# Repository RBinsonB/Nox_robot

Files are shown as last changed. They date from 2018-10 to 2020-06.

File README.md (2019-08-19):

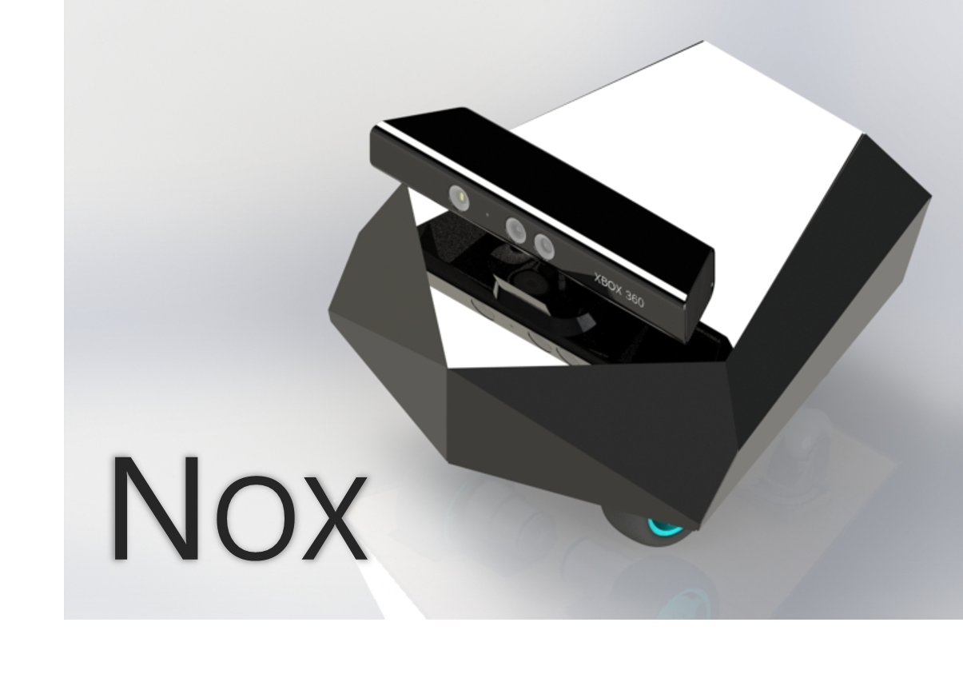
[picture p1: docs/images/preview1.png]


# Nox Robot project
Nox is a nice (and time-consuming for me) robot which uses SLAM (ROS) with a Kinect to navigate in its environment. It is powered by ROS running on a Raspberry Pi 3B and an Arduino that controls two motors with encoders.

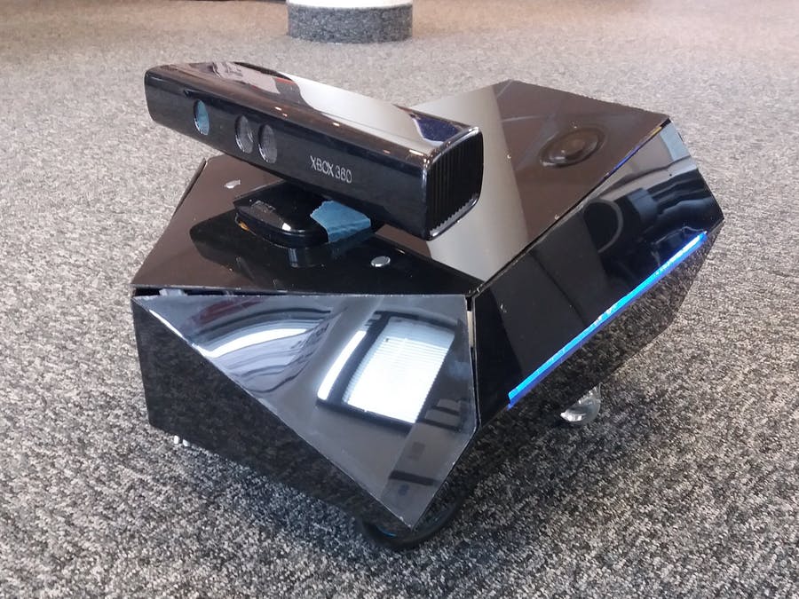
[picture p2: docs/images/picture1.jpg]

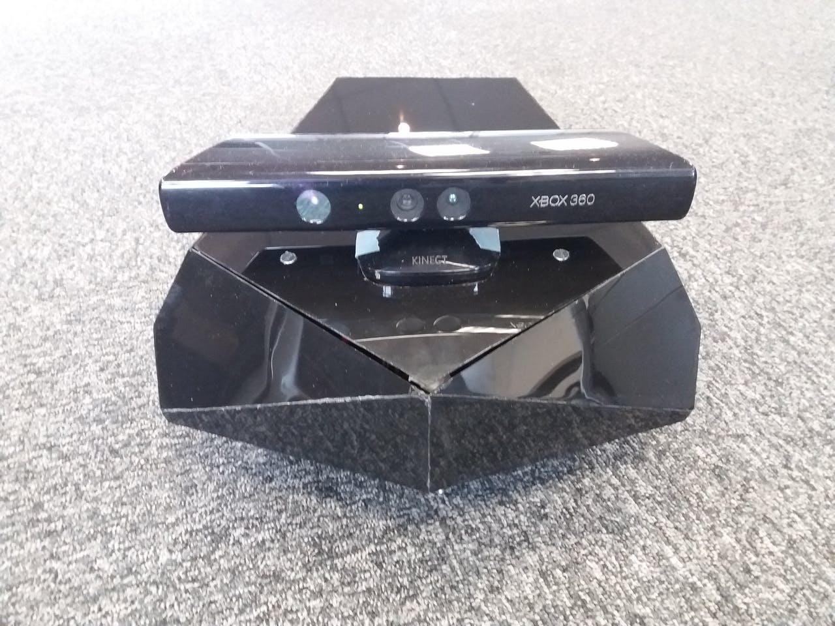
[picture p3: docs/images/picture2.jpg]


In its current state the robot can use SLAM (gmapping) to create a map of its surroundings (using the Kinect depth perception to detect wall and obstacles) and localize itself within the map. It can plan a path to a given goal and drive to it avoiding obstacles.

## Nox characteristics
Nox is a differential drive robot with the motors placed on the same axis. The base is made of wood with two caster wheels for support. The rest of the structure is made mainly of wood and metal brackets, easy to find in any DIY retail store. On the rear part of the robot plates can be stacked to put the electronic boards on.
More information (such as components used) can be found in the [Hackster page of the project](https://www.hackster.io/robinb/nox-a-house-wandering-robot-ros-652315).

### Schematics
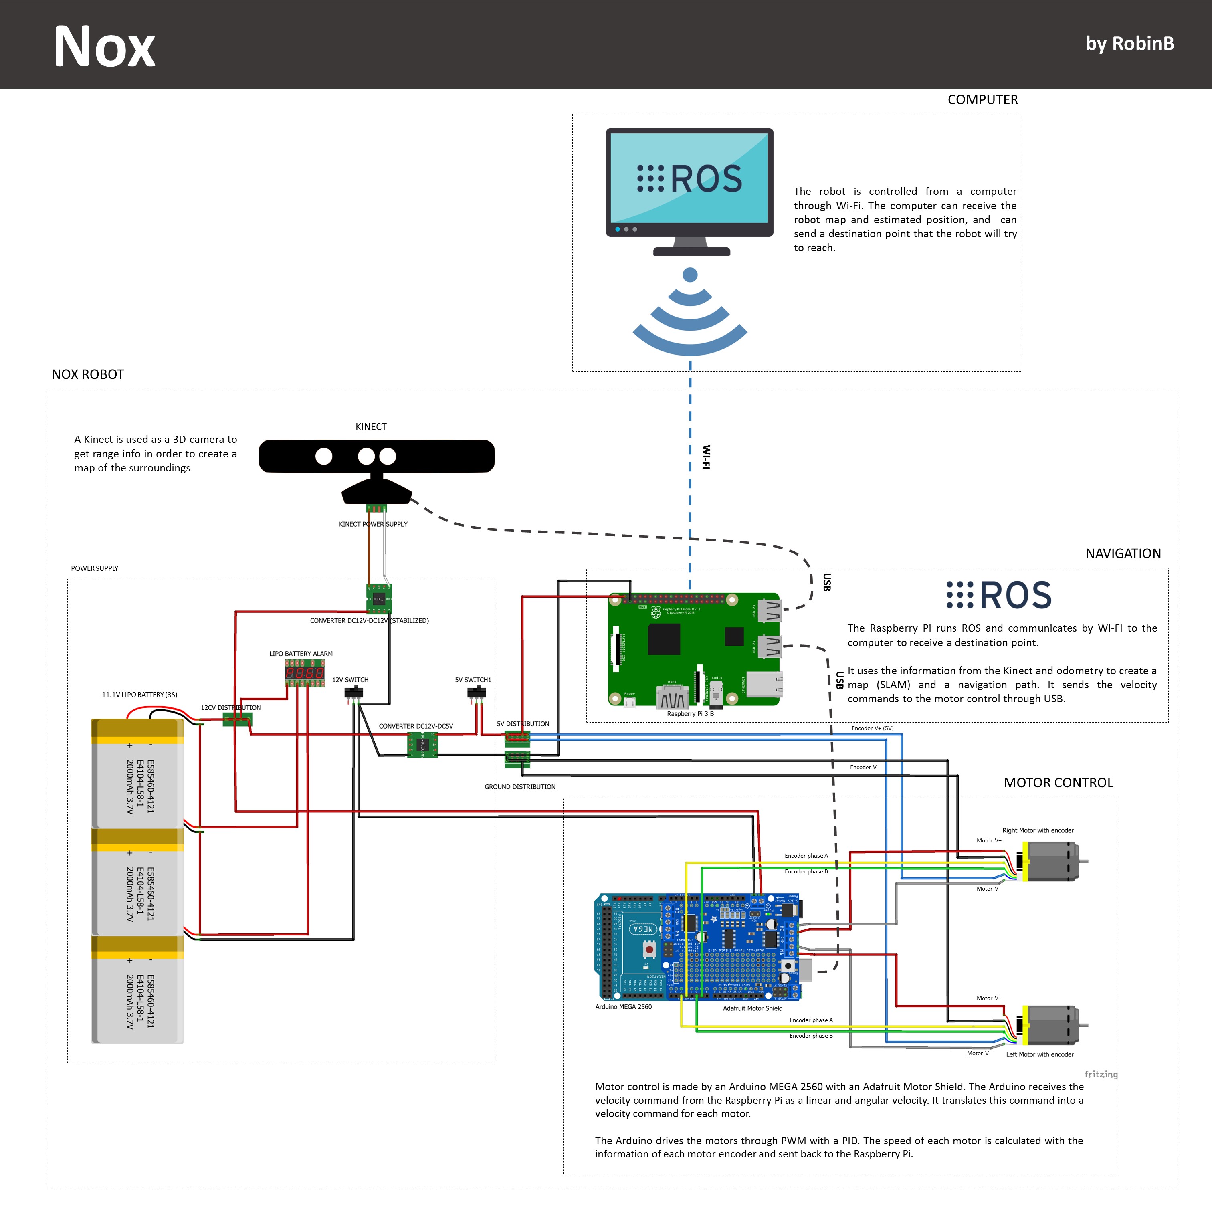
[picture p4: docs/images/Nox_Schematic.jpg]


### ROS packages
* #### nox_description:
This package includes the URDF description of the robot and the associated CAD files for display in RViz. The launch file "nox_rviz.launch" launches the joint and robot state publisher as well as RViz to display the model.
* #### nox:
This package includes the base controller node "nox_controller.cpp". This node will convert velocity command data into proper command data for the robot (according to the robot kinematic model) and send it to the Arduino Mega (through ROSSerial). It also computes the odometry (with the encoder data and according to the robot kinematic model) from data received from the Arduino Mega. The package also includes several launch files used to start the navigation (see "How to use Nox" below).
* #### Arduino:
The arduino node receives the command order from the base controller node and commands the motor speeds. It also sends back the encoder data needed for the odometry to the controller node through ROSSerial.

## How to use Nox
### Packages installation
The software for the Nox project was developped with ROS Kinetic and Ubuntu 16.04. More recent versions should work as well but might require some tweaking. This readme doesn't explain how to install ROS and packages. For more information you can check the [ROS tutorials](http://wiki.ros.org/ROS/Tutorials).

#### To use Nox you will need the following packages (most of them should already be installed by default or requested when building the nox packages):
* The [navigation stack](https://wiki.ros.org/navigation),
* The freenect package (for connecting to the Kinect)
* [RViz](http://wiki.ros.org/rviz)
* [TF](http://wiki.ros.org/tf), [Joint State](http://wiki.ros.org/joint_state_publisher) and [Robot State](http://wiki.ros.org/robot_state_publisher) Publishers
* [ROSSerial package](http://wiki.ros.org/rosserial) (for connecting to the Arduino Mega)
* [SLAM gmapping](https://wiki.ros.org/slam_gmapping).
* [TEB local planner](https://wiki.ros.org/teb_local_planner).

#### Installation
You can install and build the package by copying the "nox" and "nox_description" folders in "your_catkin_workspace/src" on both your computer and the Raspberry Pi and running:
  ```
  catkin_make
  ```

## Running Nox

In order to navigate Nox you will need to start two launch files using SSH and [ROS nodes over network](http://wiki.ros.org/ROS/NetworkSetup).
### 1. Connect to Nox Wi-Fi
I haven't included in my GitHub the RPi network configuration but basically the RPi creates an Ad-Hoc network I connect to with my computer in order to send SSH commands. It's also possible to connect both the Rpi and the computer to the same WiFi network. Once connected and before launching any ROS command you should sync the RPi to the computer using the following code in RPi:

`sudo ntpdate ip_address_of_the_computer`

You can also setup the ntpdate or use chrony to do that automatically.

### 2. Start the odometry and motor control
In the RPi, use the following command to start the main program:

`roslaunch nox nox_bringup.launch`

It will launch the serial controller node connected to the Arduino, the Kinect node, the odometry calculation node and the joint state publisher. If this step succeded you should see the side light of the robot going from a series of three quick blinks to a slow "breathing-like" type of blinking.

### 3. Start the navigation
In order to be able to do path planning calculation and mapping you have to use a launch file on your computer this time. Before doing so, assure yourself that you exported the ROS master from the RPi (modify the command to suit your own setup):

`export ROS_MASTER_URI=http://localhost:11311`

You can then launch:

`roslaunch nox nox_slam.launch`

It will launch the move_base node and RViz. By using the "2D Nav Goal" arrow you can give a goal for the robot to reach. Alternatively, you can use the ROS teleop keyboard to control the robot:

`rosrun teleop_twist_keyboard teleop_twist_keyboard.py` 

## Authors

* **Robin Baran** - *Initial work*

## License

This project is licensed under the GNU General Public License version 3

## Acknowledgments

* [Sungjik's project](https://sungjik.wordpress.com/2015/09/28/my_personal_robotic_companion/) which was the biggest inspiration to make my own robot
* ["ROS Navigation Tuning Guide"](http://kaiyuzheng.me/documents/navguide.pdf) by Kaiyu Zheng
* ["How to connect Kinect to Raspberry Pi 2 or 3 with ROS"](https://www.youtube.com/watch?v=_QpNMJEAkX0) Youtube video by Robotics Weekends
* ["Communication between Raspberry Pi and PC (ROS)"](https://github.com/mktk1117/six_wheel_robot/wiki/Communication-between-Raspberry-Pi-and-PC-(ROS)) by mktk1117
* ["On Differential Drive Robot Odometry with Application to Path Planning"](https://www.researchgate.net/publication/242389452_On_Differential_Drive_Robot_Odometry_with_Application_to_Path_Planning) by Evangelos Papadopoulos and Michael Misailidis
* [Turtlebot programs](https://github.com/ROBOTIS-GIT/turtlebot3)
* [Prof. Shuro Nakajima from Wakayama University](https://www.wakayama-u.ac.jp/~nakajima/) where I got the occasion to learn by working on the PMV (Personal Mobility Vehicle) project (check it it's awesome)
* Everyone in the ROS community who got the same problems as me and those who answered them

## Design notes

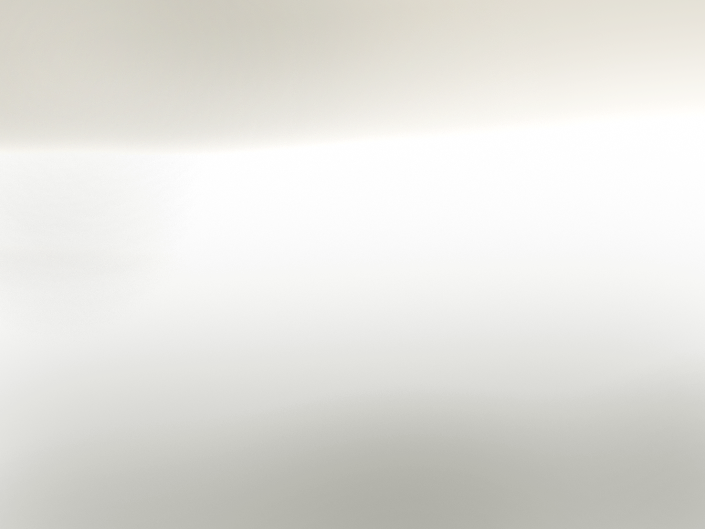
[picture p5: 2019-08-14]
CAD/Solidworks/Arduino Uno/snowcloud.png

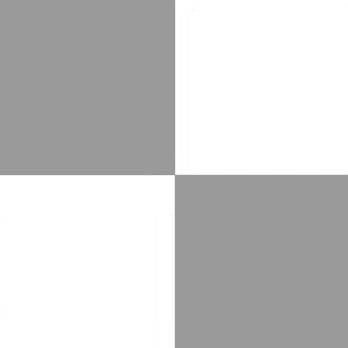
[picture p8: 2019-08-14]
CAD/Solidworks/Arduino Uno/checker3.jpg

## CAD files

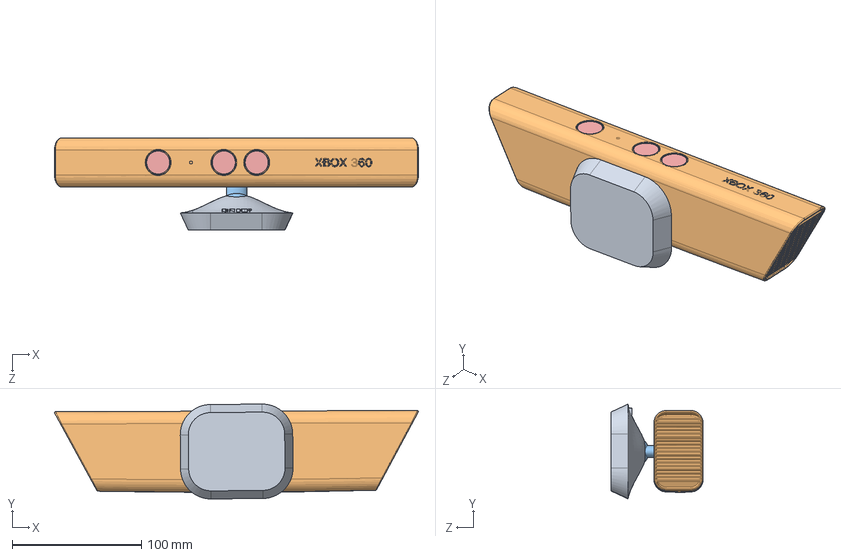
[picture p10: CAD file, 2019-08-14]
CAD/Solidworks/Kinect/kinect assembly.SLDASM
281.5 x 73.4 x 71.4 mm
kinect base
kinect
kinect pivot
kinect middle lightbulb x 2
kinect lens cover x 3

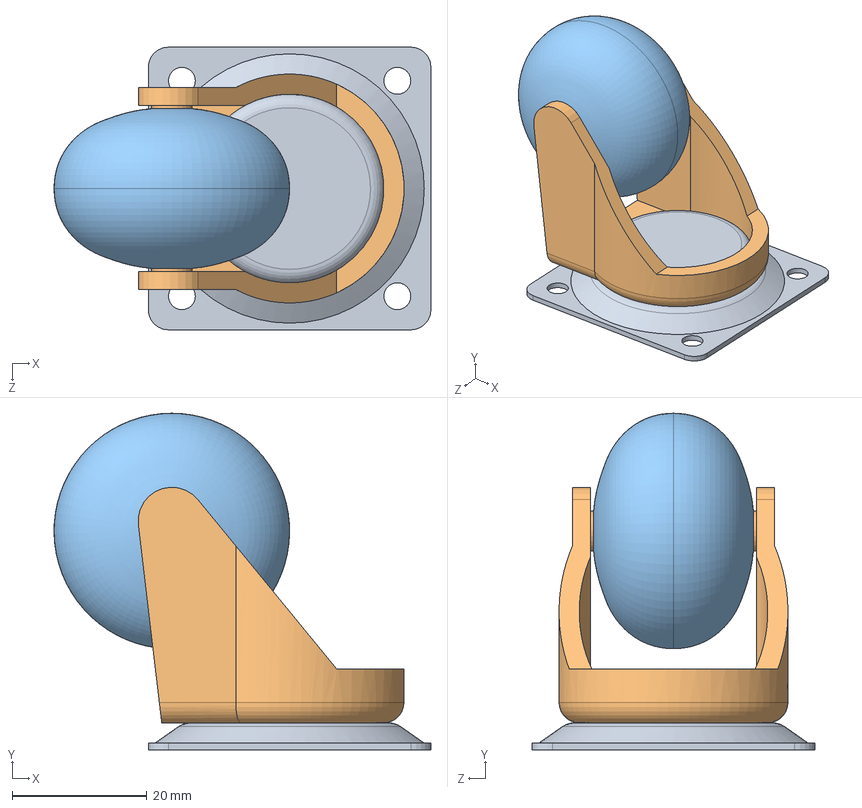
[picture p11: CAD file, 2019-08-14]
CAD/Solidworks/Pivoting roller/Pivoting_roller.SLDASM
56.0 x 50.0 x 42.0 mm
roller_base
Pivot
Roller

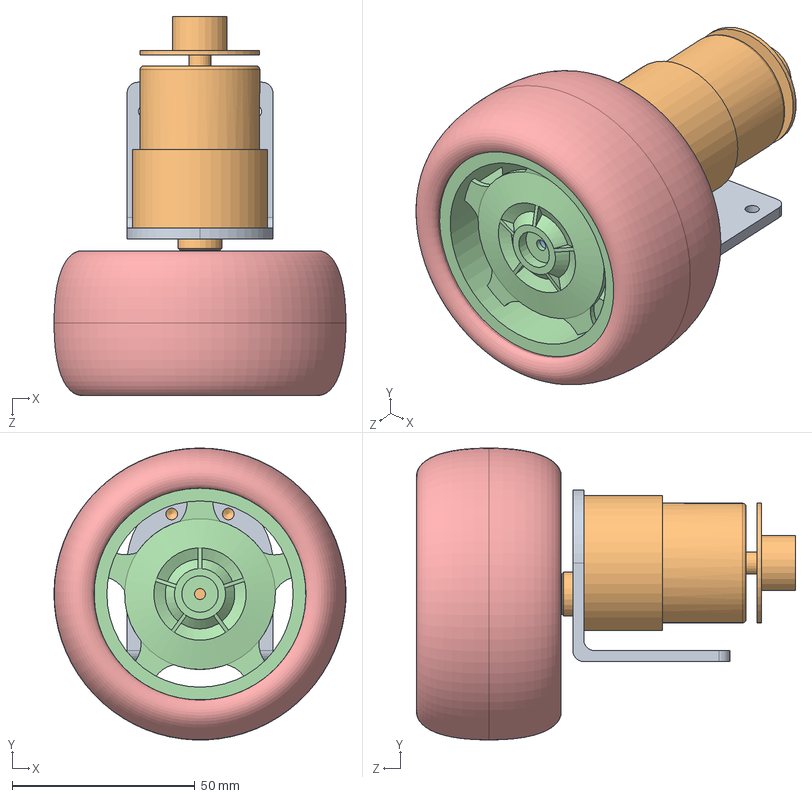
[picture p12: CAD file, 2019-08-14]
CAD/Solidworks/Motor/Motor_assembly.SLDASM
80.0 x 80.0 x 103.8 mm
Support
Moteur
Attache_moteur
Roue
Pneu

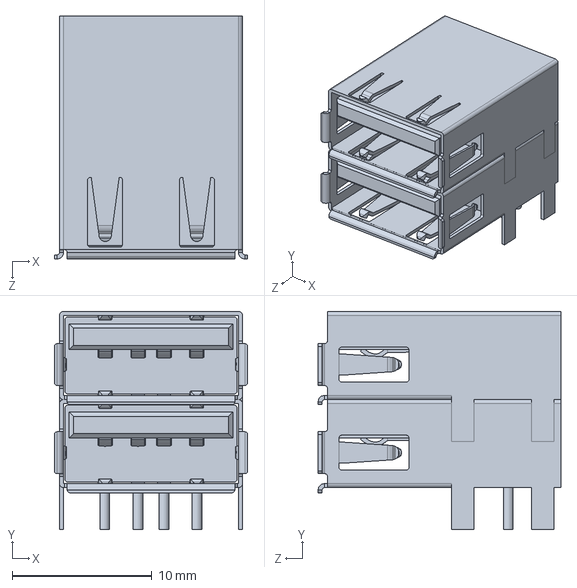
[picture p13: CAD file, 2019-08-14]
CAD/Solidworks/Raspberry Pi Model B 3/dual_usb.SLDASM
13.8 x 15.6 x 17.4 mm
USB port x 2

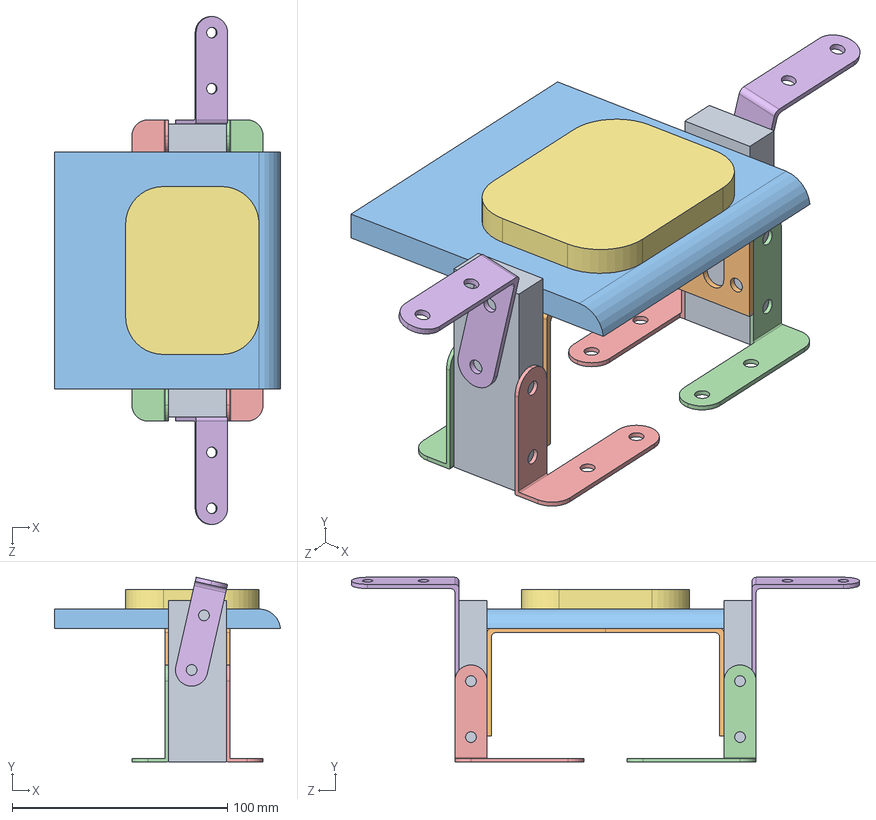
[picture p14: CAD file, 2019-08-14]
CAD/Solidworks/Kinect support/Kinect support.SLDASM
105.0 x 85.8 x 236.0 mm
wood_block x 2
Mounting_bracket_50 x 2
wood_planck_kinect
Angle iron left x 2
Angle iron right x 2
Angle small 50 x 2
wedge_kinect

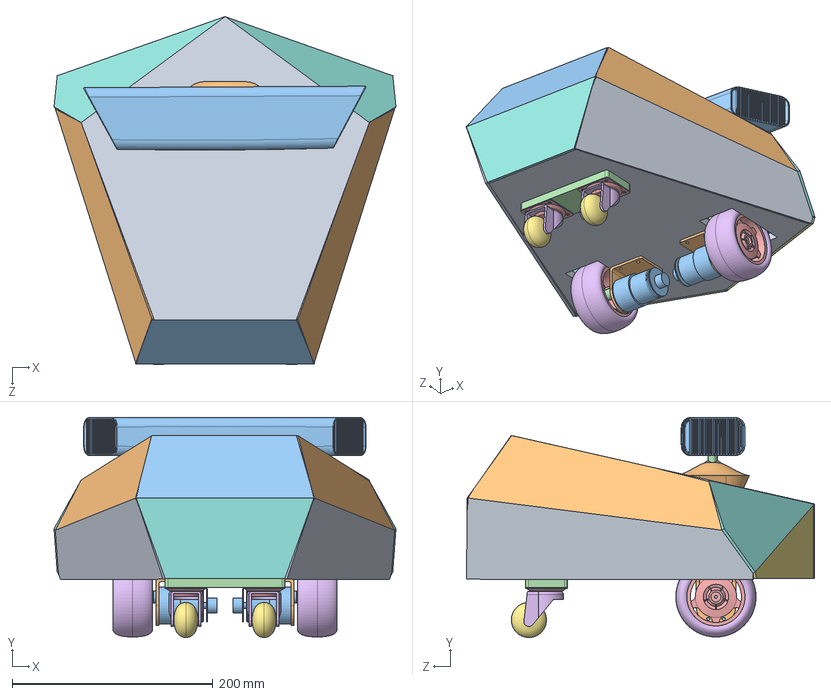
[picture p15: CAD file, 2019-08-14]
CAD/Solidworks/Nox.SLDASM
341.0 x 219.4 x 347.0 mm
base
Support x 2
Moteur x 2
Attache_moteur x 2
Roue x 2
Pneu x 2
Front_left x 2
Front_left_superior x 2
Top
kinect base
kinect
kinect pivot
kinect middle lightbulb x 2
kinect lens cover x 3
Battery_11v
Rear
Left_bottom x 2
Left_top x 2
Rear_top
Mounting_bracket x 4
PCB
rj45 port
USB port x 4
pins
audio jack
15pin FFC x 2
ffc lid x 2
wood_block x 2
Mounting_bracket_50 x 2
wood_planck_kinect
Angle iron left x 2
Angle iron right x 2
Angle small 50 x 2
wedge_kinect
rear_support
Roller_wedge
roller_base x 2
Pivot x 2
Roller x 2
Angle small 30 x 4
Electronic support
Frame_front_left_1 x 2
Frame_front_left_2 x 2
Frame_front_left_3 x 2
Frame_front_left_5 x 2
Frame_front_center_1
Frame_front_center_2
Frame_left_1
Frame_left_2 x 3
Frame_left_3
Frame_rear_1 x 2

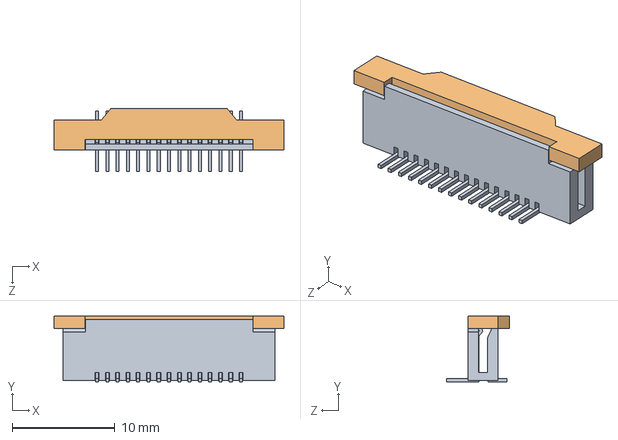
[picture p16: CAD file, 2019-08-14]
CAD/Solidworks/Raspberry Pi Model B 3/FFC.SLDASM
22.4 x 6.38 x 6.11 mm
15pin FFC
ffc lid

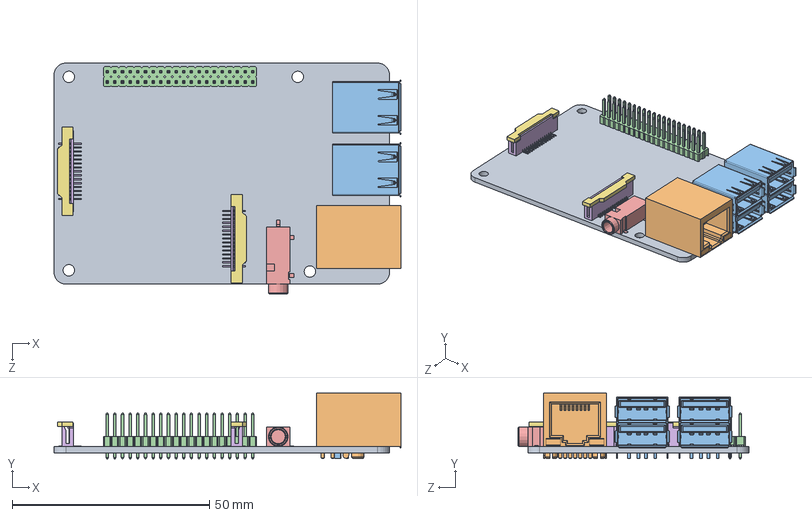
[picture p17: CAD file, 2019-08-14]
CAD/Solidworks/Raspberry Pi Model B 3/raspberry pi model B+.SLDASM
87.9 x 16.6 x 58.5 mm
PCB
rj45 port
USB port x 4
pins
audio jack
15pin FFC x 2
ffc lid x 2

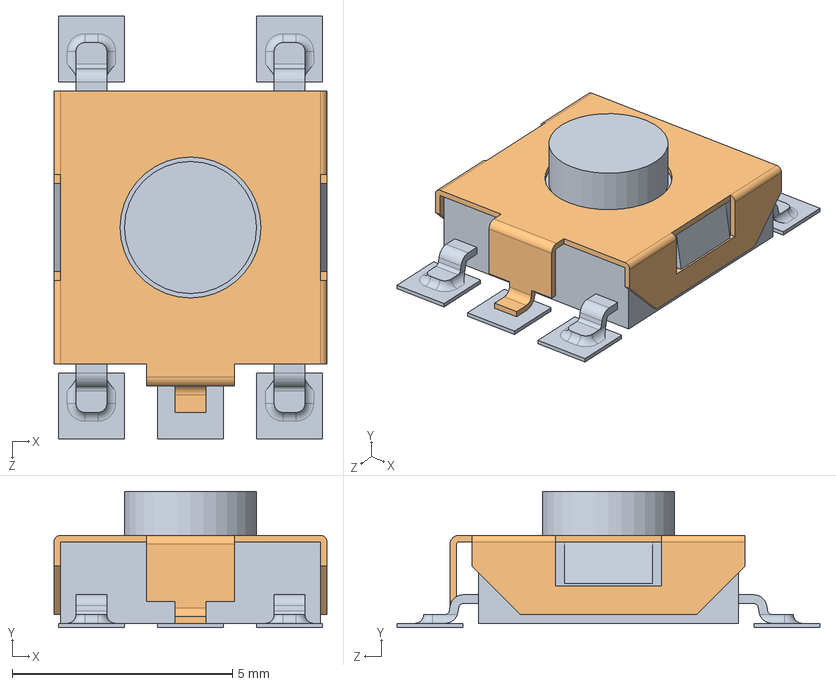
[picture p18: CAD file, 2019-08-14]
CAD/Solidworks/Arduino Uno/RESET BUTTON.SLDASM
6.20 x 3.10 x 9.60 mm
RESET CORE
RESET

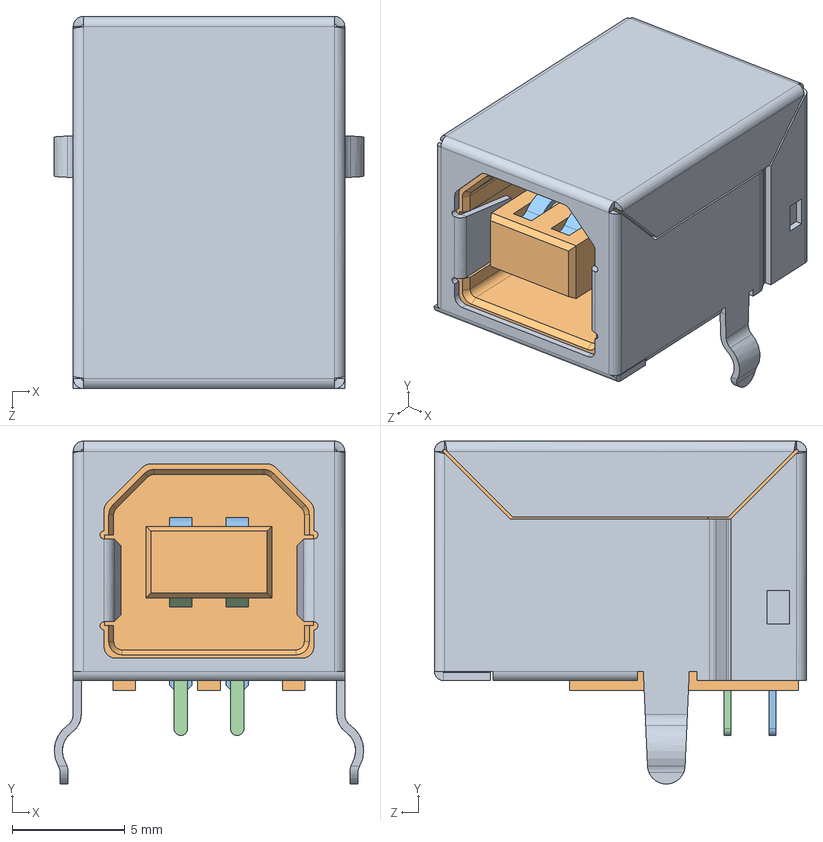
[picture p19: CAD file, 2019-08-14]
CAD/Solidworks/Arduino Uno/USB type b.SLDPRT.SLDASM
13.7 x 15.2 x 16.5 mm
USB SHELL
USB core
usb top contact x 2
usb btm contact x 2

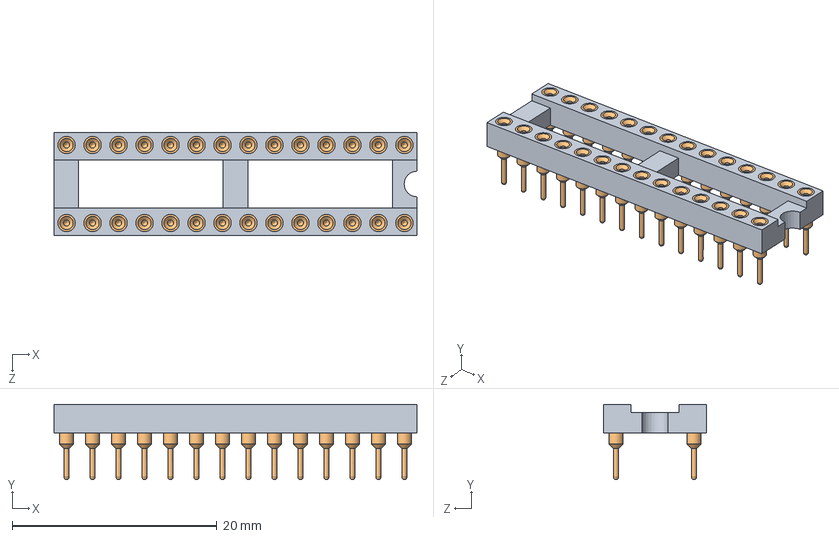
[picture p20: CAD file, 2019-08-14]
CAD/Solidworks/Arduino Uno/dip28.SLDASM
35.5 x 7.37 x 10.1 mm
dip28
dip socket pin x 28

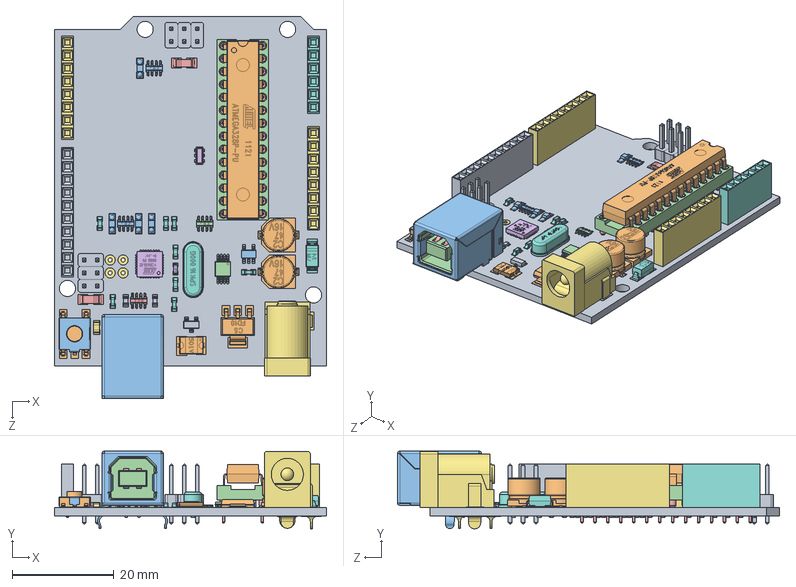
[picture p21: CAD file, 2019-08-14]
CAD/Solidworks/Arduino Uno/arduino uno.SLDASM
53.3 x 15.2 x 74.9 mm
unoboard blue
47uf CAP Dcase x 2
USB SHELL
USB core
usb top contact x 2
usb btm contact x 2
power jack
crystal
2pin_header__02 x 6
nano - reg
led x 4
dip28
dip socket pin x 28
atmega16u2
8 PORT HEADER x 2
6 PORT HEADER
10 PORT HEADER
ATMEL328P
102 RESISTOR PACK x 2
103 RESISTOR PACK
220 RESISTOR PACK
16mhz crystal - measured
PADS001
603 cap on pad x 8
ssot3
mf-msmf050-2
lmv358
lp2985dgkr
cd1206 diode x 2
603 resistor
blm21
m7 diode
MLC0603 x 2
RESET CORE
RESET

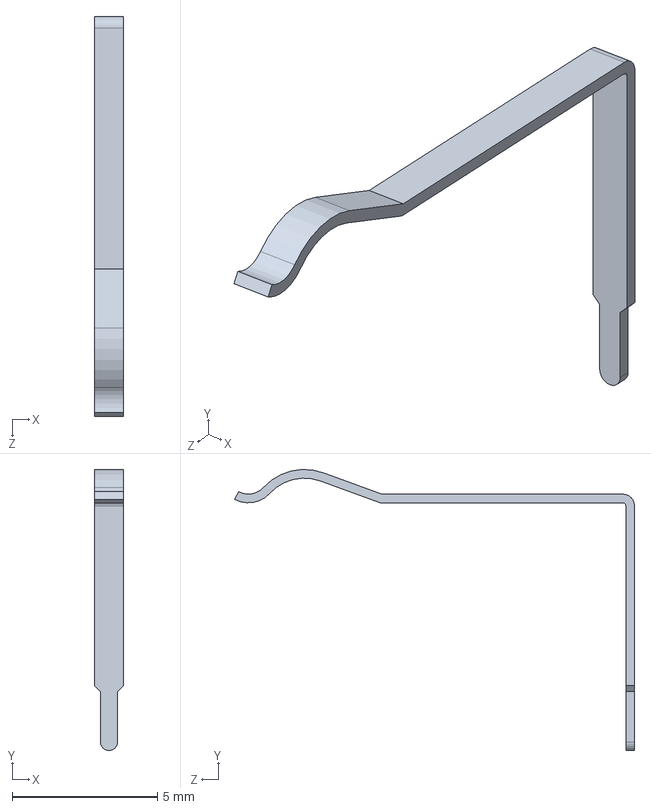
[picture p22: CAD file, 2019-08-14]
CAD/Solidworks/Arduino Uno/usb top contact.SLDPRT
1.00 x 9.67 x 13.8 mm

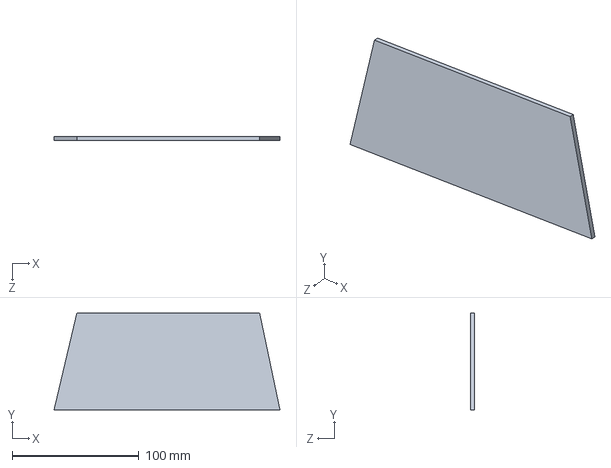
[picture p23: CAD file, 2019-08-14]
CAD/Solidworks/Carter/Rear_top.sldprt
178.2 x 76.4 x 3.00 mm

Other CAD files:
CAD/Solidworks/Frame_front_left_3.sldprt
CAD/Solidworks/Kinect support/wood_planck_kinect.SLDPRT
CAD/Solidworks/Motor/Attache_moteur.SLDPRT
CAD/Solidworks/Pivoting roller/Roller.SLDPRT
CAD/Solidworks/Angle small 30.SLDPRT
CAD/Solidworks/Angle small 50.SLDPRT
CAD/Solidworks/Arduino Uno/10 PORT HEADER.SLDPRT
CAD/Solidworks/Arduino Uno/102 RESISTOR PACK.SLDPRT
CAD/Solidworks/Arduino Uno/103 RESISTOR PACK.SLDPRT
CAD/Solidworks/Arduino Uno/16mhz crystal - measured.SLDPRT
CAD/Solidworks/Arduino Uno/220 RESISTOR PACK.SLDPRT
CAD/Solidworks/Arduino Uno/2pin_header__02.sldprt
CAD/Solidworks/Arduino Uno/47uf CAP Dcase.SLDPRT
CAD/Solidworks/Arduino Uno/6 PORT HEADER.SLDPRT
CAD/Solidworks/Arduino Uno/603 cap on pad.SLDPRT
CAD/Solidworks/Arduino Uno/603 resistor.SLDPRT
CAD/Solidworks/Arduino Uno/8 PORT HEADER.SLDPRT
CAD/Solidworks/Arduino Uno/ATMEL328P.SLDPRT
CAD/Solidworks/Arduino Uno/MLC0603.SLDPRT
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

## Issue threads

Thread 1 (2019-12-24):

arduino firmware

bekirbostanci, 2019-12-24:
Hello
Your arduino firmware there is lots of different variable and some constant values. Some of them don't have any comment. Can you write comment for these lines ?
```
//990 and 1000 ?
speed_act_left=((pos_left/990)*2*PI)*(1000/LOOPTIME)*radius;   

//0.882 and 0.00235 ?
PWM_leftMotor = constrain(((speed_req_left+sgn(speed_req_left)*0.0882)/0.00235) + (speed_cmd_left/0.00235), -255, 255);
```

bekirbostanci, 2019-12-27:
0.00235 is a scale factor to turn the speed in m/s into PWM value (0 to 255)
The coefficient is a slof of the pwm and cmd value.
Second coefficient is dead range of the motor driver so that we are adding sgn(speed_req_left)*0.0882
Thanks @RBinsonB

Closed 2019-12-27.

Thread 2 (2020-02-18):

Wiring diagram does not agree with arduino code

madgrizzle, 2020-02-18:
I think the wiring diagram shows pins 2, 3, 5, & 6 being used for the encoder inputs but the arduino code uses 2, 3, 4, & 5.  Made my robot go in circles on rviz.

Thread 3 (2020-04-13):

RPi lanch problem

DPiero, 2020-04-13:
Hi,
forgive my english .. it's really bad ..
I have a problem with your project.
when i launch roslaunch nox nox_bringup.launch on Rpi
everything is ok except this:
[joint_state_publisher-1] process has died [pid 3887, exit code -6, cmd /home/ubuntu/catkin_ws/src/joint_state_publisher/joint_state_publisher/scripts/joint_state_publisher __name:=joint_state_publisher __log:=/home/ubuntu/.ros/log/b7e3dfe8-7d05-11ea-9aa0-080027e45c80/joint_state_publisher-1.log].
log file: /home/ubuntu/.ros/log/b7e3dfe8-7d05-11ea-9aa0-080027e45c80/joint_state_publisher-1*.log
since odometry doesn't work, could this be the problem?

bekirbostanci, 2020-04-13:
Hi Piero
Our repo only include arduino code. There is not a launcher in my pid dc
motor project.
So that I dont know how can I help you
Can you describe little bit more your problem

DPiero <notifications@github.com>, 13 Nis 2020 Pzt, 03:17 tarihinde şunu
yazdı:

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

2sekFPV, 2020-08-19:
Hi all !!!

Awsome project, thanks a lot for sharing :-)

But I'm facing the same issue with the joint state publisher dying... and so in Rviz I've got both "No transform from kinect to base_link" and "No transform from wheel_left to base_link"...

nbaddorf, 2020-11-17:
I think that I found out how to solve your problem. if you go into Nox_robot/nox/launch/nox_bringup.launch look for where it says gui and then True. chainge the True to False and that fixed it for me.

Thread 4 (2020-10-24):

arduino code

Ktysai, 2020-10-24:
Hello!

A wonderful job! Can you help me a little bit with the speed_to_pwm ration. How did you obtain it?

All the best!

bekirbostanci, 2020-10-24:
Hi @Ktysai
const double speed_to_pwm_ratio = 0.00235;    //Ratio to convert speed (in m/s) to PWM value. It was obtained by plotting the wheel speed in relation to the PWM motor command (the value is the slope of the linear function).

In the ros we are use cmd_vel topics for the control diff drive robots. That cmd_vel topics message type is  geometry_msgs::Twist  and this message include linear_x and angular_z. You can calculate motor speeds for this information. That is the first part.

We are coming your question. What is the speed_to_pwm_ratio constant. This constant convert wheel speed to pwm. Firstly you have to give 255 pwm your motor and detect the your motor max rpm. That is your max motor speed. After this process you have to calculate your circumference of the wheel. 2*pi*your_wheel_radius. After circumference*(rpm/60) give meter/sec. This is your speed but still this unit is not pwm.

Result :
For example my max speed 1 m/sec. Computer send the 1 m/sec with cmd_vel I have convert the pwm with this constant. If we know the max_rpm of my motor I can calculate this coefficient.
 ```
circumference = 2*pi*your_wheel_radius
max_speed = circumference*(max_rpm/60)
speed_to_pwm_ratio = (max_speed/255)
```

 I tried to explain in detail as much as I could, if there is another topic I can help with,  feel free to ask.

Ktysai, 2020-10-24:
@bekirbostanci  👍
Lovely explanation and an over all good project for ROS beginners as my self! The ROS is not that problematic as hardware interface :)

Practically you've given it a test in real life, not the specification given by the manufacturer. I guess the test is with no load, with wheels not touching the surface.

The minimum speed is tested with the robot with all the components mounted?

I was testing the Sungjik version with some modifications of the project, but sometimes with a joystick command
given in ROS, the wheels were rolling a little bit in the opposite direct of the movement and then were ok, with the right speed and direction. The <PID_v1.h> seems to work well here.

In my case I use an Leonardo clone and I'll have to do some tweaking since the dinamic memory is used a lot the by program.

When I've tested the robot I've had a encoder malfunction and the wheel was starting to go wild due to PID. I'll try to do a nocommloop thingy, that I've seen it's implemented here like `if no_encoder_ticks AND PWM_command is_not 0, then PWM = 0`. Is the proper way?

Thanks for the work and for in for provided!

All the best,
Ktysai

bekirbostanci, 2020-10-24:
It has been a long time since I used this project. As far as I remember, although we used a brushed dc motor, the result was not very efficient although the pid worked correctly. If you think your data from your encoders are incorrect and the encoder counts incorrectly, it is quite natural that the motor will speed up and cannot be controlled. Since the parameter you will enter here will be the same for 2 wheels and it will be balanced with pid, I think you do not need to adjust it very precisely.

Ktysai, 2020-10-24:
No, problem!

I want to go into the BLDC, but the ones with encoders aren't that cheap, plus a proper controllers, so for tests I'll still use them.
With BLDC, the torque is really high even at low speeds?

bekirbostanci, 2020-10-24:
Yes normally bldc motors torque control is not very easy task. There are some different methods for example foc field oriented control. You can search if you want to control more properly

Ktysai, 2020-10-27:
I know you've said it was a long time ago since the code was developed., but maybe you have a hint.

A big chunk of my code is based on yours, but I've had a lot of trouble in making the motor to obey the maximum speed.

The following line: **speed_cmd_left** is used to control the, but the motor speed exceeds the maxim speed.

https://github.com/RBinsonB/Nox_robot/blob/d7c528e78952625da7269b7a0c0fdce362763913/Arduino/motor_controller_v2_AFMS/motor_controller_v2_AFMS.ino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

If the **speed_cmd_left** is changed with **speed_req_left** the speed of the motor is properly constrained.

Is there something that i miss in my code?

bekirbostanci, 2020-10-27:
Hi again
This line only limited your cmd_left value.
speed_cmd_left = constrain(speed_cmd_left, -max_speed, max_speed);

Actually I don't know the problem completely know. If your encoder get true value and kp ki kd values are appropriate,  bellow line code should  convert your speed value to pwm.
`PWM_leftMotor = constrain(((speed_req_left+sgn(speed_req_left)*min_speed_cmd)/speed_to_pwm_ratio) + (speed_cmd_left/speed_to_pwm_ratio), -255, 255); `

If you are know limited your motor speed somethings goes to wrong. Maybe encoders not count all pulse but it is unlikely.
But you can check your encoder this way. Write a small arduino code and give motor to 255 pwm and encoders also count all pulse. Before the starting code  keep a counter ready and start both arduino code and counter at the same time check how many pulses you get after 60 seconds and calculate the expected value and compare your expected value and measured total pulse. If this 2 values are close pid values is not correct I think.

Ktysai, 2020-10-31:
@bekirbostanci, thanks again!

If I look at the rostopic "speed", **speed_req_left** & **speed_req_left** looks as expected. **speed_cmd_left** is changing very fast, but the numbers usually are far beyond the required speed, no matter what maximum speed is specified. Maybe is a displaying issue, since the topic is not refreshed that often. I have not used the serial of arduino to debug, yet :((

Encoders seems to be ok, I'll recheck them anyway, since it's easy to have a mismatched constant there. I'm using **[these](https://www.pololu.com/product/4753)** motors.

I'll have to recheck the code again, to be sure that there's no improper ratio involved. At the moment with **speed_req_left** constrained the code works.

The idea of constraining the **speed_req_left**  was born after seeing that **speed_cmd_left** might be already constrained by this line.
https://github.com/RBinsonB/Nox_robot/blob/d7c528e78952625da7269b7a0c0fdce362763913/Arduino/motor_controller_v2_AFMS/motor_controller_v2_AFMS.ino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

In any case, a lovely code that helps a lot development.

All the best!

Agri-Mechatronic, 2022-08-02:
> It has been a long time since I used this project. As far as I remember, although we used a brushed dc motor, the result was not very efficient although the pid worked correctly. If you think your data from your encoders are incorrect and the encoder counts incorrectly, it is quite natural that the motor will speed up and cannot be controlled. Since the parameter you will enter here will be the same for 2 wheels and it will be balanced with pid, I think you do not need to adjust it very precisely.

Hello, can we use differential drive (diff_tf.py) instead of nox_controller.cpp.If yes do you think that will effect in efficiency.Thanks.

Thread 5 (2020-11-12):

USING WITH RPLIDAR A1.

manhtran98bg, 2020-11-12:
Hi, i am doing an project like you project but i have used RPlidar A1 instead KINECT. So i want to ask you how to create launch file to use with RPlidar A1( i use motor with encoder  and arduino + pi3 like you). Pls help me! Thanks you very much!

Agri-Mechatronic, 2022-08-02:
> Hi, i am doing an project like you project but i have used RPlidar A1 instead KINECT. So i want to ask you how to create launch file to use with RPlidar A1( i use motor with encoder and arduino + pi3 like you). Pls help me! Thanks you very much!

Did you solve the problem? If yes can u answer please i am trying to do same project like yours.

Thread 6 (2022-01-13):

Adding IMU

adityasivaraj, 2022-01-13:
Hi Robin,

I am working on a similar project. I am also using Arduino to give the motor commands. Do you think I should add IMU to the RasPi directly (using GPIO pins) or I should add it to Arduino, which is already controlling the motor?

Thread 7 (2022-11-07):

LOST SYNC WITH DEVICE

Priyam1204, 2022-11-07:
WHen connecting to rplidar and running the  launch file, one error keeps on coming i.e., *LOST SYN TO DEVICE, RESTARTING*

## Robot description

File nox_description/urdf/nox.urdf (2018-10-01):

<?xml version="1.0"?>
	<robot name="nox">
		<link name="base_link">
			<visual>
				<origin rpy="1.57075 0 -1.57075" xyz="0.095 0.1664 0.05"/>
				<geometry>
					<mesh filename="package://nox_description/meshes/base.STL" scale="0.001 0.001 0.001"/>
				</geometry>
				<material name="black">
       			<color rgba="0.1 0.1 0.1 1"/>
     			</material>
			</visual>
		</link>

		<link name="motor_left">
			<visual>
				<origin rpy="-1.57075 0 0" xyz="-0.02 -0.061 0"/>
				<geometry>
					<mesh filename="package://nox_description/meshes/motor.STL" scale="0.001 0.001 0.001"/>
				</geometry>
				<material name="grey">
       			<color rgba="0.3 0.3 0.3 1"/>
     			</material>
			</visual>
		</link>

		<joint name="base_link_to_motor_left" type="fixed">
			<parent link="base_link"/>
			<child link="motor_left"/>
			<origin xyz="0 0.07 0.059"/>
		</joint>
		
		<link name="motor_right">
			<visual>
				<origin rpy="-1.57075 0 3.14159" xyz="0.02 0.061 0"/>
				<geometry>
					<mesh filename="package://nox_description/meshes/motor.STL" scale="0.001 0.001 0.001"/>
				</geometry>
				<material name="grey"/>
			</visual>
		</link>

		<joint name="base_link_to_motor_right" type="fixed">
			<parent link="base_link"/>
			<child link="motor_right"/>
			<origin xyz="0 -0.07 0.059"/>
		</joint>
		
		<link name="wheel_left">
			<visual>
				<origin rpy="1.57075 0 0" xyz="-0.04 0.02 -0.04"/>
				<geometry>
					<mesh filename="package://nox_description/meshes/wheel.STL" scale="0.001 0.001 0.001"/>
				</geometry>
				<material name="wheel_color">
       			<color rgba="0.06 0.25 0.25 1"/>
     			</material>
			</visual>
		</link>	
			
		<joint name="motor_left_to_wheel_left" type="continuous">
			<parent link="motor_left"/>
			<child link="wheel_left"/>
			<origin xyz="0 0.023 -0.019"/>
			<axis xyz="0 1 0"/>
		</joint>
		
		<link name="wheel_right">
			<visual>
				<origin rpy="1.57075 0 0" xyz="-0.04 0.02 -0.04"/>
				<geometry>
					<mesh filename="package://nox_description/meshes/wheel.STL" scale="0.001 0.001 0.001"/>
				</geometry>
				<material name="wheel_color"/>
			</visual>
		</link>	
			
		<joint name="motor_right_to_wheel_right" type="continuous">
			<parent link="motor_right"/>
			<child link="wheel_right"/>
			<origin xyz="0 -0.023 -0.019"/>
			<axis xyz="0 1 0"/>
		</joint>
		
		<link name="support_wheel_left">
			<visual>
				<origin rpy="-1.57075 0 1.57075" xyz="-0.021 -0.021 0"/>
				<geometry>
					<mesh filename="package://nox_description/meshes/support_wheel.STL" scale="0.001 0.001 0.001"/>
				</geometry>
				<material name="transparent_grey">
       			<color rgba="0.25 0.25 0.25 0.7"/>
     			</material>
			</visual>
		</link>	
			
		<joint name="base_link_to_support_wheel_left" type="fixed">
			<parent link="base_link"/>
			<child link="support_wheel_left"/>
			<origin xyz="-0.124 0.039 0.05"/>
		</joint>
		
		<link name="support_wheel_right">
			<visual>
				<origin rpy="-1.57075 0 1.57075" xyz="-0.021 -0.021 0"/>
				<geometry>
					<mesh filename="package://nox_description/meshes/support_wheel.STL" scale="0.001 0.001 0.001"/>
				</geometry>
				<material name="transparent_grey"/>
			</visual>
		</link>	
			
		<joint name="base_link_to_support_wheel_right" type="fixed">
			<parent link="base_link"/>
			<child link="support_wheel_right"/>
			<origin xyz="-0.124 -0.039 0.05"/>
		</joint>
		
		<link name="kinect">
			<visual>
				<origin rpy="0 0 1.57075" xyz="0.03 -0.14 0.04"/>
				<geometry>
					<mesh filename="package://nox_description/meshes/kinect_sensor.stl" scale="0.01 0.01 0.01"/>
				</geometry>
				<material name="black"/>
			</visual>
		</link>

		<joint name="base_link_to_kinect" type="continuous">
			<parent link="base_link"/>
			<child link="kinect"/>
			<origin xyz="-0.0065 0 0.139"/>
			<axis xyz="0 1 0"/>
		</joint>	
		
	</robot>

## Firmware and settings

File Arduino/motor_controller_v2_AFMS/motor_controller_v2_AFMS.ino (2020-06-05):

#include <Adafruit_MotorShield.h>
#include <Wire.h>
#include <PID_v1.h>
#include <ros.h>
#include <std_msgs/String.h>
#include <geometry_msgs/Vector3Stamped.h>
#include <geometry_msgs/Twist.h>
#include <ros/time.h>
 
//initializing all the variables
#define LOOPTIME                      100     //Looptime in millisecond
const byte noCommLoopMax = 10;                //number of main loops the robot will execute without communication before stopping
unsigned int noCommLoops = 0;                 //main loop without communication counter

double speed_cmd_left2 = 0;      

const int PIN_ENCOD_A_MOTOR_LEFT = 2;               //A channel for encoder of left motor                    
const int PIN_ENCOD_B_MOTOR_LEFT = 4;               //B channel for encoder of left motor

const int PIN_ENCOD_A_MOTOR_RIGHT = 3;              //A channel for encoder of right motor         
const int PIN_ENCOD_B_MOTOR_RIGHT = 5;              //B channel for encoder of right motor 

const int PIN_SIDE_LIGHT_LED = 46;                  //Side light blinking led pin

unsigned long lastMilli = 0;

//--- Robot-specific constants ---
const double radius = 0.04;                   //Wheel radius, in m
const double wheelbase = 0.187;               //Wheelbase, in m
const double encoder_cpr = 990;               //Encoder ticks or counts per rotation
const double speed_to_pwm_ratio = 0.00235;    //Ratio to convert speed (in m/s) to PWM value. It was obtained by plotting the wheel speed in relation to the PWM motor command (the value is the slope of the linear function).
const double min_speed_cmd = 0.0882;          //(min_speed_cmd/speed_to_pwm_ratio) is the minimum command value needed for the motor to start moving. This value was obtained by plotting the wheel speed in relation to the PWM motor command (the value is the constant of the linear function).

double speed_req = 0;                         //Desired linear speed for the robot, in m/s
double angular_speed_req = 0;                 //Desired angular speed for the robot, in rad/s

double speed_req_left = 0;                    //Desired speed for left wheel in m/s
double speed_act_left = 0;                    //Actual speed for left wheel in m/s
double speed_cmd_left = 0;                    //Command speed for left wheel in m/s 

double speed_req_right = 0;                   //Desired speed for right wheel in m/s
double speed_act_right = 0;                   //Actual speed for right wheel in m/s
double speed_cmd_right = 0;                   //Command speed for right wheel in m/s 
                        
const double max_speed = 0.4;                 //Max speed in m/s

int PWM_leftMotor = 0;                     //PWM command for left motor
int PWM_rightMotor = 0;                    //PWM command for right motor 
                                                      
// PID Parameters
const double PID_left_param[] = { 0, 0, 0.1 }; //Respectively Kp, Ki and Kd for left motor PID
const double PID_right_param[] = { 0, 0, 0.1 }; //Respectively Kp, Ki and Kd for right motor PID

volatile float pos_left = 0;       //Left motor encoder position
volatile float pos_right = 0;      //Right motor encoder position

PID PID_leftMotor(&speed_act_left, &speed_cmd_left, &speed_req_left, PID_left_param[0], PID_left_param[1], PID_left_param[2], DIRECT);          //Setting up the PID for left motor
PID PID_rightMotor(&speed_act_right, &speed_cmd_right, &speed_req_right, PID_right_param[0], PID_right_param[1], PID_right_param[2], DIRECT);   //Setting up the PID for right motor

Adafruit_MotorShield AFMS = Adafruit_MotorShield();  // Create the motor shield object with the default I2C address
Adafruit_DCMotor *leftMotor = AFMS.getMotor(1);      //Create left motor object
Adafruit_DCMotor *rightMotor = AFMS.getMotor(2);     //Create right motor object
  
ros::NodeHandle nh;

//function that will be called when receiving command from host
void handle_cmd (const geometry_msgs::Twist& cmd_vel) {
  noCommLoops = 0;                                                  //Reset the counter for number of main loops without communication
  
  speed_req = cmd_vel.linear.x;                                     //Extract the commanded linear speed from the message

  angular_speed_req = cmd_vel.angular.z;                            //Extract the commanded angular speed from the message
  
  speed_req_left = speed_req - angular_speed_req*(wheelbase/2);     //Calculate the required speed for the left motor to comply with commanded linear and angular speeds
  speed_req_right = speed_req + angular_speed_req*(wheelbase/2);    //Calculate the required speed for the right motor to comply with commanded linear and angular speeds
}

ros::Subscriber<geometry_msgs::Twist> cmd_vel("cmd_vel", handle_cmd);   //create a subscriber to ROS topic for velocity commands (will execute "handle_cmd" function when receiving data)
geometry_msgs::Vector3Stamped speed_msg;                                //create a "speed_msg" ROS message
ros::Publisher speed_pub("speed", &speed_msg);                          //create a publisher to ROS topic "speed" using the "speed_msg" type

const int lightIncNumber = 30;                                                                                                                                       //Number of lightIncrements for side light blinking
int lightInc = 0;                                                                                                                                                    //Init increment for side light blinking
int lightValue [lightIncNumber]= { 10, 40, 80, 160, 255, 255, 255, 255, 255, 255, 255, 255, 255, 255, 255, 255, 255, 255, 160, 80, 40, 10, 0, 0, 0, 0, 0, 0, 0, 0 }; //side light increment values
int lightValueNoComm [25]= { 255, 0, 255, 0, 255, 0, 0, 0, 0, 0, 0, 0, 0, 0, 0, 0, 0, 0, 0, 0, 0, 0, 0, 0, 0 }; //side light increment values
int lightT = 0; //init light period

//__________________________________________________________________________

void setup() {

  
  pinMode(PIN_SIDE_LIGHT_LED, OUTPUT);      //set pin for side light leds as output
  analogWrite(PIN_SIDE_LIGHT_LED, 255);     //light up side lights
  
  nh.initNode();                            //init ROS node
  nh.getHardware()->setBaud(57600);         //set baud for ROS serial communication
  nh.subscribe(cmd_vel);                    //suscribe to ROS topic for velocity commands
  nh.advertise(speed_pub);                  //prepare to publish speed in ROS topic
 
  AFMS.begin();
  
  //setting motor speeds to zero
  leftMotor->setSpeed(0);
  leftMotor->run(BRAKE);
  rightMotor->setSpeed(0);
  rightMotor->run(BRAKE);
 
  //setting PID parameters
  PID_leftMotor.SetSampleTime(95);
  PID_rightMotor.SetSampleTime(95);
  PID_leftMotor.SetOutputLimits(-max_speed, max_speed);
  PID_rightMotor.SetOutputLimits(-max_speed, max_speed);
  PID_leftMotor.SetMode(AUTOMATIC);
  PID_rightMotor.SetMode(AUTOMATIC);
    
  // Define the rotary encoder for left motor
  pinMode(PIN_ENCOD_A_MOTOR_LEFT, INPUT); 
  pinMode(PIN_ENCOD_B_MOTOR_LEFT, INPUT); 
  digitalWrite(PIN_ENCOD_A_MOTOR_LEFT, HIGH);                // turn on pullup resistor
  digitalWrite(PIN_ENCOD_B_MOTOR_LEFT, HIGH);
  attachInterrupt(0, encoderLeftMotor, RISING);

  // Define the rotary encoder for right motor
  pinMode(PIN_ENCOD_A_MOTOR_RIGHT, INPUT); 
  pinMode(PIN_ENCOD_B_MOTOR_RIGHT, INPUT); 
  digitalWrite(PIN_ENCOD_A_MOTOR_RIGHT, HIGH);                // turn on pullup resistor
  digitalWrite(PIN_ENCOD_B_MOTOR_RIGHT, HIGH);
  attachInterrupt(1, encoderRightMotor, RISING);
}

//_________________________________________________________________________

void loop() {
  nh.spinOnce();
  if((millis()-lastMilli) >= LOOPTIME)   
  {                                                                           // enter timed loop
    lastMilli = millis();
    
    if (!nh.connected()){
      analogWrite(PIN_SIDE_LIGHT_LED, lightValueNoComm[lightInc]);
      lightInc=lightInc+1;
      if (lightInc >= 25){
        lightInc=0;
      }
    }
    else{
      analogWrite(PIN_SIDE_LIGHT_LED, lightValue [lightInc]);
      lightT = 3000 - ((2625/max_speed)*((abs(speed_req_left)+abs(speed_req_right))/2));
      lightInc=lightInc+(30/(lightT/LOOPTIME));
      if (lightInc >= lightIncNumber){
        lightInc=0;
      }
    }
    
    
    if (abs(pos_left) < 5){                                                   //Avoid taking in account small disturbances
      speed_act_left = 0;
    }
    else {
      speed_act_left=((pos_left/encoder_cpr)*2*PI)*(1000/LOOPTIME)*radius;           // calculate speed of left wheel
    }
    
    if (abs(pos_right) < 5){                                                  //Avoid taking in account small disturbances
      speed_act_right = 0;
    }
    else {
    speed_act_right=((pos_right/encoder_cpr)*2*PI)*(1000/LOOPTIME)*radius;          // calculate speed of right wheel
    }
    
    pos_left = 0;
    pos_right = 0;

    speed_cmd_left = constrain(speed_cmd_left, -max_speed, max_speed);
    PID_leftMotor.Compute();                                                 
    // compute PWM value for left motor. Check constant definition comments for more information.
    PWM_leftMotor = constrain(((speed_req_left+sgn(speed_req_left)*min_speed_cmd)/speed_to_pwm_ratio) + (speed_cmd_left/speed_to_pwm_ratio), -255, 255); //
    
    if (noCommLoops >= noCommLoopMax) {                   //Stopping if too much time without command
      leftMotor->setSpeed(0);
      leftMotor->run(BRAKE);
    }
    else if (speed_req_left == 0){                        //Stopping
      leftMotor->setSpeed(0);
      leftMotor->run(BRAKE);
    }
    else if (PWM_leftMotor > 0){                          //Going forward
      leftMotor->setSpeed(abs(PWM_leftMotor));
      leftMotor->run(BACKWARD);
    }
    else {                                               //Going backward
      leftMotor->setSpeed(abs(PWM_leftMotor));
      leftMotor->run(FORWARD);
    }
    
    speed_cmd_right = constrain(speed_cmd_right, -max_speed, max_speed);    
    PID_rightMotor.Compute();                                                 
    // compute PWM value for right motor. Check constant definition comments for more information.
    PWM_rightMotor = constrain(((speed_req_right+sgn(speed_req_right)*min_speed_cmd)/speed_to_pwm_ratio) + (speed_cmd_right/speed_to_pwm_ratio), -255, 255); // 

    if (noCommLoops >= noCommLoopMax) {                   //Stopping if too much time without command
      rightMotor->setSpeed(0);
      rightMotor->run(BRAKE);
    }
    else if (speed_req_right == 0){                       //Stopping
      rightMotor->setSpeed(0);
      rightMotor->run(BRAKE);
    }
    else if (PWM_rightMotor > 0){                         //Going forward
      rightMotor->setSpeed(abs(PWM_rightMotor));
      rightMotor->run(FORWARD);
    }
    else {                                                //Going backward
      rightMotor->setSpeed(abs(PWM_rightMotor));
      rightMotor->run(BACKWARD);
    }

    if((millis()-lastMilli) >= LOOPTIME){         //write an error if execution time of the loop in longer than the specified looptime
      Serial.println(" TOO LONG ");
    }

    noCommLoops++;
    if (noCommLoops == 65535){
      noCommLoops = noCommLoopMax;
    }
    
    publishSpeed(LOOPTIME);   //Publish odometry on ROS topic
  }
 }

//Publish function for odometry, uses a vector type message to send the data (message type is not meant for that but that's easier than creating a specific message type)
void publishSpeed(double time) {
  speed_msg.header.stamp = nh.now();      //timestamp for odometry data
  speed_msg.vector.x = speed_act_left;    //left wheel speed (in m/s)
  speed_msg.vector.y = speed_act_right;   //right wheel speed (in m/s)
  speed_msg.vector.z = time/1000;         //looptime, should be the same as specified in LOOPTIME (in s)
  speed_pub.publish(&speed_msg);
  nh.spinOnce();
  nh.loginfo("Publishing odometry");
}

//Left motor encoder counter
void encoderLeftMotor() {
  if (digitalRead(PIN_ENCOD_A_MOTOR_LEFT) == digitalRead(PIN_ENCOD_B_MOTOR_LEFT)) pos_left++;
  else pos_left--;
}

//Right motor encoder counter
void encoderRightMotor() {
  if (digitalRead(PIN_ENCOD_A_MOTOR_RIGHT) == digitalRead(PIN_ENCOD_B_MOTOR_RIGHT)) pos_right--;
  else pos_right++;
}

template <typename T> int sgn(T val) {
    return (T(0) < val) - (val < T(0));
}

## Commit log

2018-10-01 Reuploaded nox_description
    [base.STL, kinect_sensor.stl, motor.STL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]
2018-10-01 Added arduino code
2019-08-14 Added CAD files and pictures
    [10 PORT HEADER.SLDPRT, 102 RESISTOR PACK.SLDPRT, 103 RESISTOR PACK.SLDPRT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]
2019-08-14 Adding pictures and schematics
2019-08-14 Added pictures and schematics
2020-03-05 Added constants and comments for the motor command
    Motor command constant values are now proper constants and better commented.
2020-03-16 Updated for use with the new Joint State Publisher GUI
